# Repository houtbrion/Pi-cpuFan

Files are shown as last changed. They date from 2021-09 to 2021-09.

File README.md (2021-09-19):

# Pi-cpuFan
Raspberry Piを自宅で24時間運転することを考慮すると，エアコン無しでも
熱で壊れないことが重要．
ヒートシンクも存在するが，やはり心配なのでファンを入れることにした．
ただし，24時間ファンが回るとうるさいので，システムの温度が上昇したときだけ
まわるようにしたかった．

そのため，本リポジトリの内容は，Raspberry Pi用のCPU温度に応じて冷却ファンを制御するためのハードとプログラム．
プログラムはgo言語版とshellスクリプト版の2種類を添付しています．
perl版はファン制御用のピン番号を変更する場合，ファンを回すCPU温度を
変更する場合はソースを修正する必要がありますが，go版はconfigファイルを修正するだけで
対応することができます．

## 1. 動作環境
- OS :  Raspberry Pi OS (旧Raspbian)

## 2. ソフトウェア
インストールに必要なツールの情報やインストールの手順はgo言語版プログラムは
goディレクトリ以下のREADME.md，perl版はperlディレクトリ内のREADME.mdに
記載してあります．両方見て，どちらのバージョンを利用するか判断してください．

## 3. その他の添付ファイル
- hardwareディレクトリ : [CADソフト(Fritzing)][fritzing]で作成した回路図やケースの自作例
- toolsディレクトリ : 動作確認，デバッグ用のshellスクリプト

## 4. ハードウェア構成
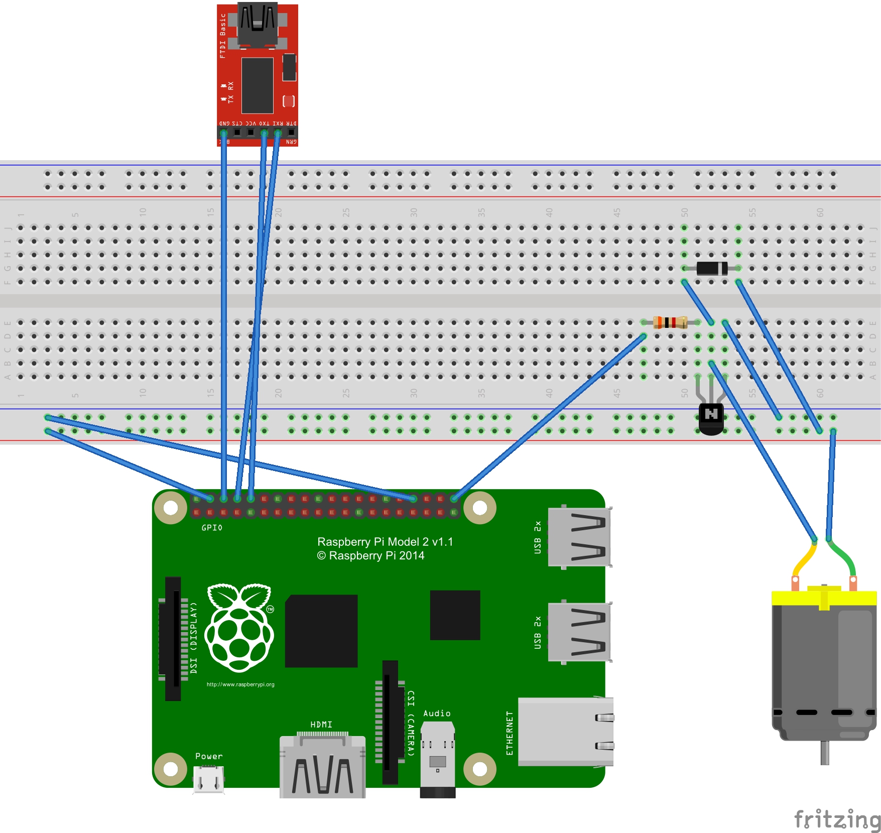
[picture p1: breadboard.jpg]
配線イメージ
では，GPIO16番にファンを制御する回路をつけることが前提になっていますが，
特に特定のGPIOピンでなければならないわけではありません．

制御用のピンを直接ファンにつなげることもできますが，Raspberry PiのGPIOのピンは電圧も3Vで電流も制限されるため，
上記の回路図とブレッドボードでの配線図はRaspberry PiのGPIOピンを制御回路につなぎ，その制御回路で
ファンを制御しています．

制御回路はトランジスタでできており，制御用のピンの電圧がHighになるとトランジスタファンに電流が流れます．
ファンは5Vの端子につながっているため，GPIOの3Vのピンに比べて多くの電力がファンに供給できます．

また，ファンと並列につながっているダイオードは制御時に電流が逆流しないようにするために入れています．

[fritzing]: <https://fritzing.org/> "fritzing"
[breadboard]: breadboard.jpg "ブレッドボード図面"
[Pi-CoolingFan]: <https://github.com/houtbrion/Pi-CoolingFan> "Pi-CoolingFan repository"
[golang]: https://go.dev/ "go公式サイト"

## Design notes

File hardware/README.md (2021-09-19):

# ハードウェア

そのディレクトリには，Raspberry Pi用のユニバーサル基板を利用してファン制御回路のシールドを作成する
場合のfritzingの回路図をだけでなく，「コンソールなど用Piシールド」では，コンソール用USBシリアル，
I2C接続のRTC端子を追加．このシールドで利用したRTCモジュールは
Spark FunのBOB-12708です．あと，秋月電子通商でも入手が容易な8564NBの場合の回路図も
付けてあります．

# 1. ここで紹介する試作ハードについて
ファン制御，RTCなどの回路を使って，Raspberry Piによるシリアルをコンソールとして利用する小型のサーバ(ディスプレイ，キーボードなど無し)
を作成し，ケースに収める試作の実例を紹介します．

ただし，コンソール用の端子は通常使われているRS-232などではなく，USBシリアルコンバータを
Raspberry PiのHATとして実装しているため，メンテナンスでネットワークが利用できない場合は
USB接続でログインすることができます．

# 2. コンソールやRTCの設定
## 2.1 Raspberry Pi3のシリアルコンソールの問題 (4は未検証)
UARTの速度がCPUの動作周波数と連動してしまうため，シリアルコンソールでは
文字化け，入力不可能な状態が続く．

[参考URL](https://github.com/RPi-Distro/repo/issues/22)

この試作では，ディスプレイやUSBキーボードを繋がず，
シリアルコンソール使うため，Raspberry Pi OSを
マイクロSDに書き込んだ際に，ブート用コンフィグファイル(/boot/config.txt)に以下の行を追加しておく．

### Pi3の場合
```
enable_uart=1
core_freq=250
```

### Pi2, Pi zeroやzeroWの場合
```
enable_uart=1
```

## 2.2 RTC
Raspberry PiはRTCが搭載されていないため，NTPなどで時刻を同期しないと人手で時刻をメンテナンス必要が
出てしまい，非常に面倒である．
この面倒を避けるため，今回の試作では，シリアルコンソール用のシールドにRTCも搭載している．
これを利用するため，以下のURLを参照し，パッケージのインスールや設定を行う．

なお，今回試作したHATは8564NBを搭載しているため，まったく同じ回路を利用する場合は後者の方の
対処をお願いします．
### Spark Fun BOB-12708
- [DS1307関係参考URL1](<https://mynotebook.h2np.net/post/1085> "Raspberry Pi 2 にRTCモジュールをつける") Raspberry Pi 2 にRTCモジュールをつける
- [DS1307関係参考URL2](<https://learn.adafruit.com/adding-a-real-time-clock-to-raspberry-pi?view=all> "Adding a Real Time Clock to Raspberry Pi") Adding a Real Time Clock to Raspberry Pi

### (秋月)8564NB
- [8564NB関係参考URL1](<http://news.mynavi.jp/articles/2014/08/21/raspberry-pi4/002.html> "超小型PC「Raspberry Pi」で夏休み自由課題・第4回 - Raspberry Piの屋外モバイル、高層エレベーターの気圧変化を調べる") 超小型PC「Raspberry Pi」で夏休み自由課題・第4回 - Raspberry Piの屋外モバイル、高層エレベーターの気圧変化を調べる
- [8564NB関係参考URL2](<http://tomosoft.jp/design/?p=5812> "Raspberry PIへリアルタイムクロックモジュールのI2C接続") Raspberry PIへリアルタイムクロックモジュールのI2C接続

# 3. 用意した部品
## 3.1 共通
### 3.1.1 本体など
* 本体 : [Raspberry Pi 2 Model B][pi2]
* ヒートシンク : [Seeed Studio 800035001 Raspberry Pi用アルミニウム・ヒートシンク][sink]
* USBシリアル変換 : [スイッチサイエンスSSCI-010320 FTDI USBシリアル変換アダプター(5V/3.3V切り替え機能付き)][ftdi]

### 3.1.2 ファンの制御回路用
* 抵抗 : [カーボン抵抗(炭素皮膜抵抗) 1/4W 3kΩ (100本)][3kohm]
* ダイオード : [ショットキーダイオード][diode]
* トランジスタ : [トランジスタ (2SC1815GR 60V 150mA) 20個][2SC1815]

ただし，今回旧型Pi用のヒートシンクを利用したのは，旧型用は小型のヒートシンクが余分についている代わりに，熱伝導両面テープが付いているので，特別な材料とかなしに，チップに貼り付けることができるためです．

## 3.2 千石電商の箱をそのまま利用
* [Seeed Studio 114990129/141107004【ファン付き】Raspberry Pi B+専用ケース(クリア/ロゴなし/組立式)][case1]
* [Seeed Studio 114990130 Raspberry Pi B+専用ケース(クリア/ロゴなし/組立式)][case2]

GPIOの横の部品にスリットがあり，そこが折れたため，スリットがないファンなしの箱を追加で買って，部品交換しましまた．

箱の壊れた部分

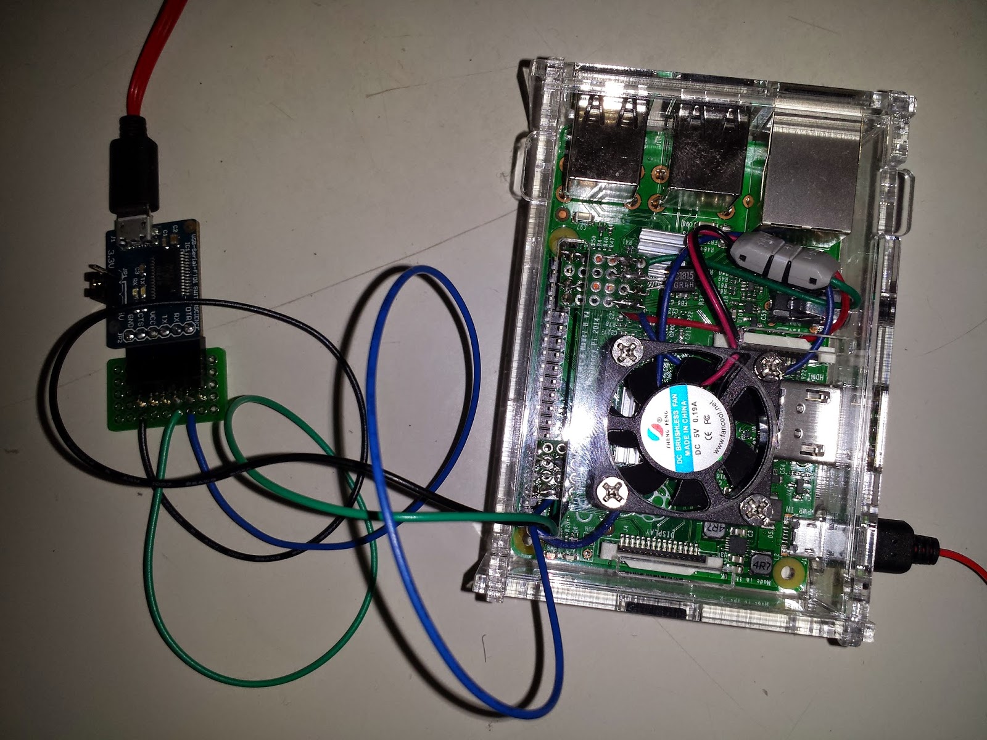
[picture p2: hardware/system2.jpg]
千石のファン付き箱に収めた写真


## 3.3 改造版
シリアルを簡単に繋げられるようにしたかったので，GPIO端子周りに余裕がある箱を改造してファンを付けた．
* [MultiComp MC-RP002-CLR Raspberry Pi B+専用ケース(クリア/ロゴあり)][case3]
* [SHICOH F4006AP-05QCW (0406-5) DCファン(5V)][dcFan]
* [カモンSRS-40 ファン防振シリコンシート][si-sheet]
* [40mm角ファンガード][FanGuard]

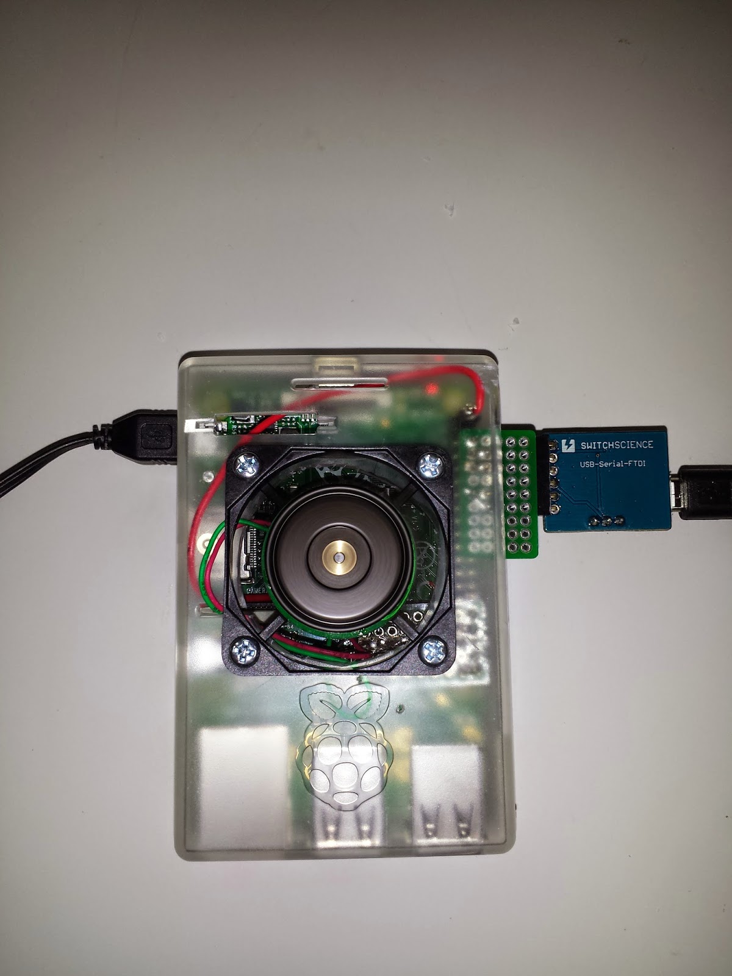
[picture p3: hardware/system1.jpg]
自作箱に収めた写真


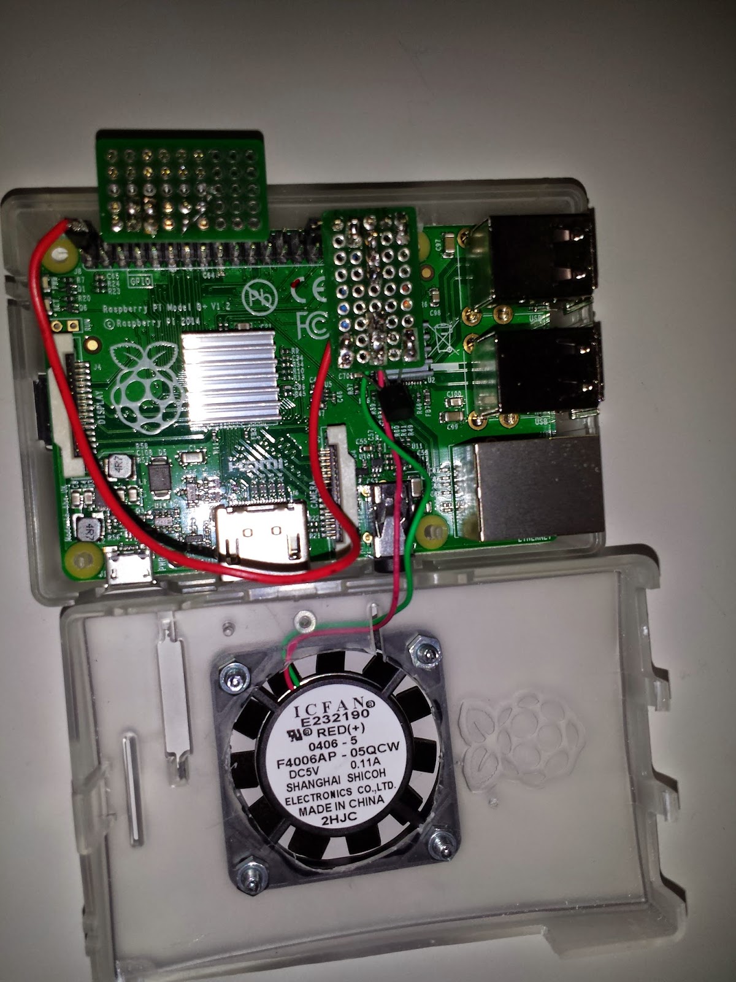
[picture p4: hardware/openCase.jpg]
自作箱を開けた写真


# 4. 回路図など
ブレッドボード利用時の配線イメージ

回路図

# 5. ハードテスト用プログラムの準備
本番運用の前に，試作したハードがきちんと動作するか確認する必要があるため，
[toolsディレクトリ](../tools)内の動作確認用プログラムを利用します．

- getTemperature.sh : CPU温度を取得するプログラム
- fanOff.sh : ファン制御用回路につながるGPIOピンをLowにするプログラム
- fanOn.sh : ファン制御用回路につながるGPIOピンをHighにするプログラム

ただし，fanOff.shとfanOn.shはピン番号を試作したハードに合わせて修正する
必要があるため，以下の参考にしてください．

### fanOff.sh
下の「18」と「gpio18」を自分が用意した回路に合わせて修正．
```
    #!/bin/sh
    
    echo 18 >/sys/class/gpio/export
    echo out >/sys/class/gpio/gpio18/direction
    echo 0 > /sys/class/gpio/gpio18/value
```

### fanOn.sh
こちらも同じくGPIOの番号を修正．
```
    #!/bin/sh
    
    echo 18 >/sys/class/gpio/export
    echo out >/sys/class/gpio/gpio18/direction
    echo 1 > /sys/class/gpio/gpio18/value
```

# 6. 動作確認
上のgetTemperature.shでCPU温度が取得できることと，fanOn.sh, fanOff.shで
ファンが回ることを確認してください．

# 7. 製作記事
なお，RTC無しで小さめの箱に収めた試作は以下の記事で紹介していますので
そちらを参照してください．

## 市販の箱に収めた場合
- [市販の箱をそのまま使った場合の制作記事][sengoku]
- [試作したハード][sengoku-pic]

## 自分で箱に穴を開けて，ファンを付けた場合
- [改造箱版の制作記事][original]
- [試作したハード][original-pic]とその[内部][inside]

<!--以下はリンクの定義-->
<!--参考文献-->
[sengoku]: <http://hautbrion.blogspot.jp/2015/05/raspberry-pi-2usb-1.html> "千石の箱版"
[original]: <http://hautbrion.blogspot.jp/2014/10/raspberry-pi-2.html> "改造箱版"

<!--ハード関連-->

[pi2]: <http://akizukidenshi.com/catalog/g/gM-09024/> "Raspberry Pi 2 Model B"
[case1]: <http://www.sengoku.co.jp/mod/sgk_cart/detail.php?code=EEHD-4N4C> "Seeed Studio 114990129/141107004【ファン付き】Raspberry Pi B+専用ケース(クリア/ロゴなし/組立式)"
[case2]: <http://www.sengoku.co.jp/mod/sgk_cart/detail.php?code=EEHD-4R3F> "Seeed Studio 114990130 Raspberry Pi B+専用ケース(クリア/ロゴなし/組立式)"
[sink]: <https://www.sengoku.co.jp/mod/sgk_cart/detail.php?code=EEHD-4FBE> "Seeed Studio 800035001 Raspberry Pi用アルミニウム・ヒートシンク"
[ftdi]: <http://www.sengoku.co.jp/mod/sgk_cart/detail.php?code=EEHD-0SK8> "スイッチサイエンスSSCI-010320 FTDI USBシリアル変換アダプター(5V/3.3V切り替え機能付き)"
[3kohm]: <http://akizukidenshi.com/catalog/g/gR-25302/> "カーボン抵抗(炭素皮膜抵抗) 1/4W 3kΩ (100本)"
[diode]: <http://akizukidenshi.com/catalog/g/gI-00881/> "ショットキーダイオード"
[2SC1815]: <http://akizukidenshi.com/catalog/g/gI-00881/> "トランジスタ (2SC1815GR 60V 150mA) 20個"
[dcFan]: <https://www.sengoku.co.jp/mod/sgk_cart/detail.php?code=557S-43JV> "SHICOH F4006AP-05QCW (0406-5) DCファン(5V)"
[si-sheet]: <https://www.sengoku.co.jp/mod/sgk_cart/detail.php?code=4AZ6-GFHU> "カモンSRS-40 ファン防振シリコンシート"
[FanGuard]: <https://www.sengoku.co.jp/mod/sgk_cart/detail.php?code=328B-2CE8> "40mm角ファンガード"
[case3]: <http://www.sengoku.co.jp/mod/sgk_cart/detail.php?code=EEHD-4KRC> "MultiComp MC-RP002-CLR Raspberry Pi B+専用ケース(クリア/ロゴあり)"

<!--イメージファイル-->
[system1]: system1.jpg "自作箱に収めた写真"
[system2]: system2.jpg "千石のファン付き箱に収めた写真"
[breadboard]: breadboard.jpg "ブレッドボード利用時の配線イメージ"
[circuit]: circuit.jpg "回路図"
[openCase]: openCase.jpg "自作箱を開けた写真"
[brokenCase]: brokenCase.jpg "箱の壊れた部分"
[sengoku-pic]: system2.jpg "千石でかった箱"
[priginal-pic]: system1.jpg "穴を開けた箱"
[inside]: openCase.jpg "内部"

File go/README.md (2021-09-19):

# go言語版ソフトウェア

Raspberry Pi用の冷却ファン制御プログラムのgo言語版．

## 1. 動作環境

### 1.1 動作を確認した各種ソフトのバージョン
- OS : Raspberry Pi bullseye
- go言語 : go version go1.17 linux/arm
- periph
  - periph.io/x/conn/v3 : v3.6.8
  - periph.io/x/d2xx    : v0.0.1
  - periph.io/x/host/v3 : v3.7.0

### 1.2 ビルドに必要なその他のツール
- make

## 2. インストール
### 2.1 準備
1章のリストを見て，go言語とmakeだけはインストールしておいてください．goやmakeをインストールする際に，その他の開発ツールを入れる必要があると思いますが，それについては，go言語の[オフィシャルサイト][golang]の指示に従ってください．

### 2.2 調整
#### 2.2.1 設定ファイルの内容を回路に合わせる

GPIOのピン番号は，設定ファイル(本リポジトリのbuttonAndShutdown.cfg)で変更可能です．

以下は例であるが，ファン制御回路のGPIOの番号は「fanpin」の行で設定しており，GPIO番号16番(ピン番号36番:[参考資料][gpio_map])にしています．
```
{
	"use_syslog":true,
	"use_stdout":false,
	"log_file_name":"",
	"low_threshold":30,
	"high_threshold":40,
	"fanpin":"GPIO16"
}
```

#### 2.2.2 ログ出力先の選択
再度の掲示になりますが，設定ファイルの中身は以下のようになっています．ここで，「usesyslog」はsyslogを使うか否か，「usestdout」は標準出力にログを垂れ流す場合(回路の動作確認などに利用)，「logfilename」にログファイルのフルパスを指定すると，指定したファイルにログを追加書き込みしていきます．
```
$ cat cpufan.cfg
{
	"use_syslog":true,
	"use_stdout":false,
	"log_file_name":"",
	"low_threshold":30,
	"high_threshold":40,
	"fanpin":"GPIO16"
}
$
```
複数のログ出力先を有効にすることも可能ですし，全部ON(もしくはOFF)にするものOKです．

#### 2.2.3 CPU温度の設定
前節では，設定ファイルでGPIOのピン番号を設定しましたが，冷却用ファンを回す温度のしきい値も設定できます．このプログラムはCPUの温度が上がるとファンを回し，CPUの温度が下がるとファンを止めるため，CPU温度が「high_threshold」を超えるとファンを回し，温度が下がってき「low_threshold」を下回るとファンを止めます．ファンが止まったり動作したりを繰り替えすと音が気になるなどの影響があるため，ファンが回り始めるしきい値「high_threshold」とファンが止まるしきい値「low_threshold」をある程度差をあけてください．もちろん「high_threshold」を大きくします．

#### 2.2.4 インストール先ディレクトリの修正
現状インストール先のディレクトリは/usr/localになっています．
もし，修正したい場合は以下の項目を修正してください．

- Makefile : BASE_DIRの設定行(例:BASE_DIR=/usr/local)
- プログラム本体(cpufan.go) : 設定ファイルのフルパス(例 : const defaultConfigFileName string = "/usr/local/etc/cpufan.cfg")
- systemdの設定(cpufan.service) : バイナリパス名(例 : ExecStart=/usr/local/bin/cpufan)

### 2.3 インストール
以下の2ステップです．
- ```make all```
- ```sudo make install```

rebootで動作しますが，もし，即座に動かしたい場合は，以下のコマンドを実行してください．
```
# systemctl restart cpufan.service
```
うまく動作していれば，systemctlコマンドで「Active: active (running) since 時刻」となるはずです．
```
# systemctl status cpufan.service
● cpufan.service - cpufan
     Loaded: loaded (/etc/systemd/system/cpufan.service; enabled; vendor preset>
     Active: active (running) since Mon 2021-09-06 14:09:13 JST; 47min ago
   Main PID: 10691 (cpufan)
      Tasks: 9 (limit: 2059)
        CPU: 1.706s
     CGroup: /system.slice/cpufan.service
             mq10691 /usr/local/bin/cpufan

Sep 06 14:09:13 raspberrypi systemd[1]: Started cpufan.
#
```

[golang]: https://go.dev/ "go公式サイト"
[gpio_map]: https://www.raspberrypi.org/documentation/computers/os.html#gpio-and-the-40-pin-header "ピン配置"

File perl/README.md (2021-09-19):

# perl版
shellスクリプト版のソフトウェアは，ピン番号を変更する場合や，ファンを制御する
温度を変更する場合はソースを直接編集する必要があります．

## 1. インストール

現状は，systemctl用の定義ファイル等を作っていないので，fanctrlを適当な
ディレクトリにコピーした上で，実行手順を/etc/rc.localに追加
してください．

あと，perlとperlのSwitchモジュールを使っているので，
インストールしていない場合はインストールしてください．

## 2. パラメータ調整

以下はプログラムそのもののとなっています．
```
    #!/usr/bin/perl
    
    use Switch;
    
    open(IN, "/sys/class/thermal/thermal_zone0/temp");
    $cputemp = <IN>/1000.0; #numbers
    close(IN);
    $cputempavg = $cputemp;
    
    system("echo 18 > /sys/class/gpio/export");
    system("echo out > /sys/class/gpio/gpio18/direction");
    system("echo 1 > /sys/class/gpio/gpio18/value");
    $fan_run = 1;
    
    while(1)
    {
    	open(IN, "/sys/class/thermal/thermal_zone0/temp");
    	$cputemp = <IN>/1000.0; #numbers
    	close(IN);
    	
    	$cputempavg = $cputempavg*0.9 + $cputemp*0.1;
    
    	if($cputempavg > 45)
    	{
    		$fan_run = 1;
    	}
    	if($cputempavg < 35)
    	{
    		$fan_run = 0;
    	}
    	if($cputempavg > 65)
    	{
    		$fan_run = 2;
    	}
    	switch ($fan_run) {
    		case 1 { system("echo 1 > /sys/class/gpio/gpio18/value");}
    		case 0 { system("echo 0 > /sys/class/gpio/gpio18/value");}
    		else   { system("shutdown -h now");}
    	}
    	sleep(10);
    }
```

### 2.1. ファン制御用のピン番号
ファンを制御するピンは18番に決め打ちになっているので，ピンを変更する場合は，「fanctrl」の以下の「gpio18」をファンの制御信号のピンに変更してください．
```
    	switch ($fan_run) {
    		case 1 { system("echo 1 > /sys/class/gpio/gpio18/value");}
    		case 0 { system("echo 0 > /sys/class/gpio/gpio18/value");}
    		else   { system("shutdown -h now");}
    	}
```

ピン番号の参考文献は「[ここ][gpio_map]」です．

### 2.2. CPU温度定義

現状の「fanctrl」は45度でファンがまわり，35度でファンが止まります．ファンでは温度が下がらず65度以上になると強制シャットダウンするようになっているので，これらのしきい値は使う環境に合わせて変更してください．
```
    	if($cputempavg > 45)
    	{
    		$fan_run = 1;
    	}
    	if($cputempavg < 35)
    	{
    		$fan_run = 0;
    	}
    	if($cputempavg > 65)
    	{
    		$fan_run = 2;
    	}
```

[gpio_map]: https://www.raspberrypi.org/documentation/computers/os.html#gpio-and-the-40-pin-header "ピン配置"

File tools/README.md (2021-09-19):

# テスト用ツール
Raspberry PiのCPU温度の測定と，ファン制御用ピンの電圧を強制的にHigh,Low切り替えを行うshellスクリプトで，
ハード作成時の動作確認などに利用するものです．

各ツールの役割は名前からわかると思います．
* getTemperature.sh
* fanOff.sh
* fanOn.sh

## 1. 各プログラムの説明
### getTemperature.sh
カーネルからCPU温度を読み出しています．
```
    #!/bin/sh
    cat /sys/class/thermal/thermal_zone0/temp
```

### fanOff.sh
ピン番号を直接指定しているので，ピン番号を変更する場合はソースを編集してください．
```
    #!/bin/sh
    
    echo 18 >/sys/class/gpio/export
    echo out >/sys/class/gpio/gpio18/direction
    echo 0 > /sys/class/gpio/gpio18/value
```

### fanOn.sh
こちらもピン番号の変更には，編集が必要です．
```
    #!/bin/sh
    
    echo 18 >/sys/class/gpio/export
    echo out >/sys/class/gpio/gpio18/direction
    echo 1 > /sys/class/gpio/gpio18/value
```

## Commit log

2021-09-06 vim用定義とgo関連のワークファイルを追加．
2021-09-06 README用の図面ファイルを追加．
2021-09-06 最初のバージョンを追加
    [cpufan.cfg]
2021-09-06 最初のバージョンを追加
    プログラムの説明からインストールまで全て説明
2021-09-19 merge repository of go lang version.
    go版のリポジトリとマージ
    [CoolingFan+RTC.fzz, CoolingFan.fzz, cpufan.cfg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]
